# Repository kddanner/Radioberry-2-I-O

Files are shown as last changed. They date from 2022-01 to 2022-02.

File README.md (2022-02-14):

# Radioberry-2-I-O

==================

This is a simple companion board to the Radioberry 2.x to provide I/O and cooling. The minor circuitry used is shamelessly copied from the excellent [Radioberry 2](https://github.com/pa3gsb/Radioberry-2.x) and [Hermes-Lite 2](http://www.hermeslite.com) projects.

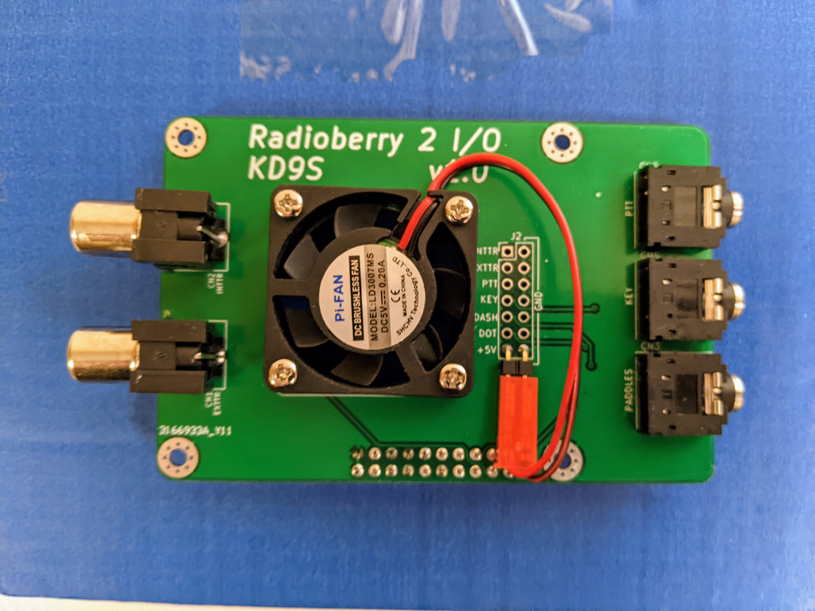
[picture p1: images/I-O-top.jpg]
Top


I tried to make this board versatile, it can be assembled multiple ways. All SMD parts are on the bottom, but all other components (header/fan/RCA jacks/3.5mm jacks) can be installed on either the top or the bottom. The board pictured has only a 2 pin header installed for the fan, but a 14 pin header can be installed for individual leads or a ribbon cable to be attached to the 5 jacks if they are mounted on a remote panel instead of directly on this board. If installing jacks on the bottom side of this board you'll need to have the SMA connectors on the bottom side of the Radioberry 2 board rather than on top as is usually done. Also, if the fan were installed on the bottom there would not be a lot of clearance between the fan and the Radioberry 2 board so you'll need low profile heatsinks and/or longer headers connecting the 2 boards to get the needed clearance. There is enough room for the I/O header to be a 90-degree header to keep the profile lower if wanted.

The zero-ohm resistors, numbered R10x are only needed when the jacks are installed on this board, and they only need to be installed in either the boxes silkscreened TOP or BTM, never both.

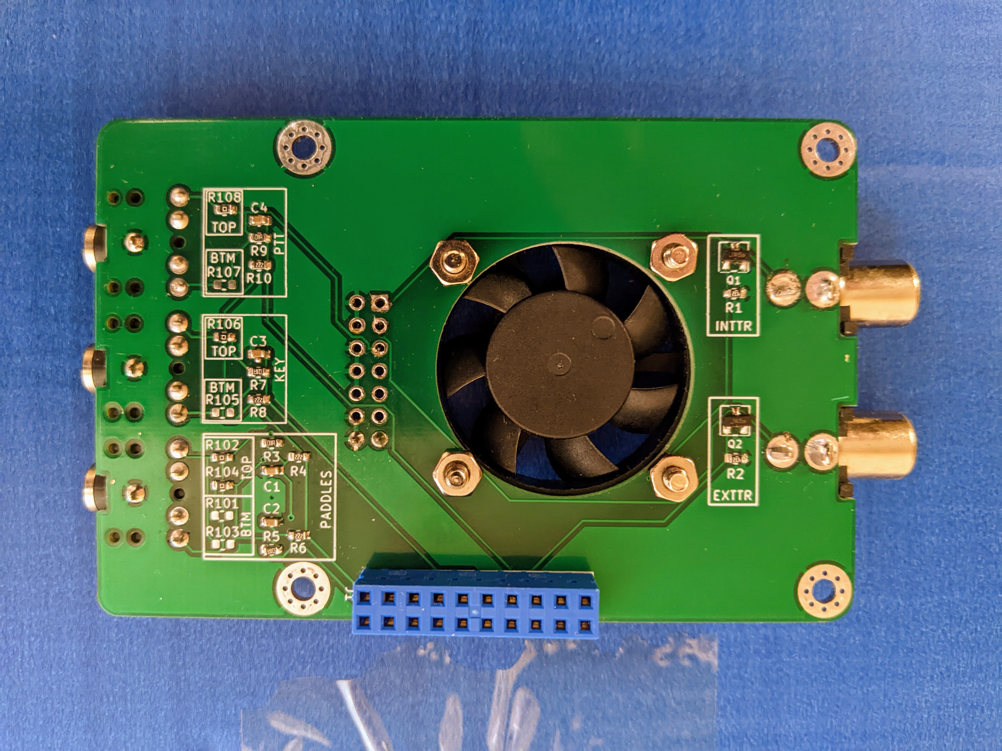
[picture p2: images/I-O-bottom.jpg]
Bottom


This cheap "case" is some of the parts from one that is meant for a pi cluster stack, available here: [Amazon link](https://www.amazon.com/gp/product/B07JP2TFJY/ref=ppx_yo_dt_b_search_asin_title?ie=UTF8&psc=1)

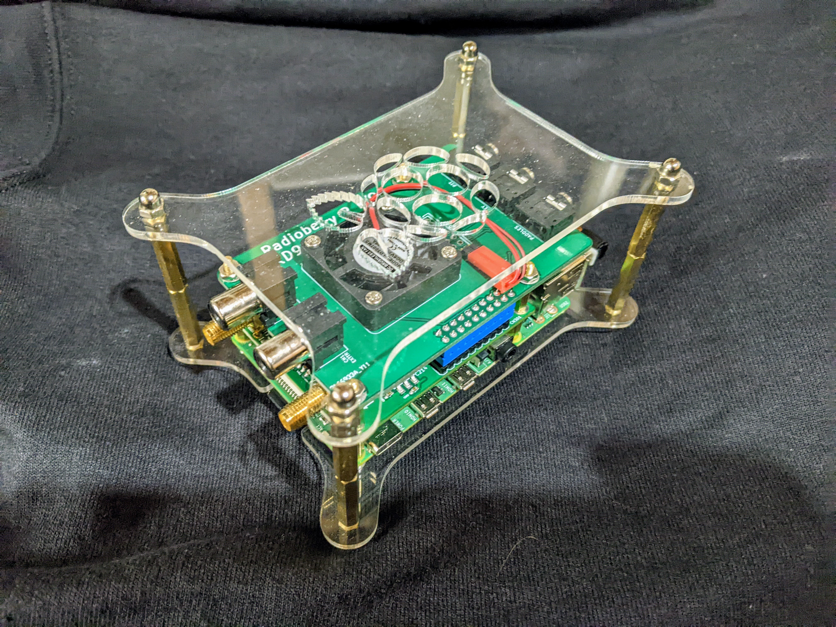
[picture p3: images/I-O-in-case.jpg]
Case


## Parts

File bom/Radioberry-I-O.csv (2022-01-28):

Source: | C:\Users\kdanner\Documents\GitHub\Radioberry-I-O\Radioberry-I-O\Radioberry-I-O.kicad_sch
Date: | 1/27/2022 5:44:45 PM
Tool: | Eeschema (6.0.1)
Generator: | C:\Program Files\KiCad\6.0\bin\scripting\plugins/bom_csv_grouped_by_value.py
Component Count: | 32
Individual Components:
Item | Qty | Reference(s) | Value | LibPart | Footprint | Datasheet | Part Number
 |  | C1 | 1uf | Device:C_Small | Capacitor_SMD:C_0603_1608Metric | https://search.murata.co.jp/Ceramy/image/img/A01X/G101/ENG/GRM188R61E105KAAD-01.pdf | GRM188R61E105KAADD
 |  | C2 | 1uf | Device:C_Small | Capacitor_SMD:C_0603_1608Metric | https://search.murata.co.jp/Ceramy/image/img/A01X/G101/ENG/GRM188R61E105KAAD-01.pdf | GRM188R61E105KAADD
 |  | C3 | 1uf | Device:C_Small | Capacitor_SMD:C_0603_1608Metric | https://search.murata.co.jp/Ceramy/image/img/A01X/G101/ENG/GRM188R61E105KAAD-01.pdf | GRM188R61E105KAADD
 |  | C4 | 1uf | Device:C_Small | Capacitor_SMD:C_0603_1608Metric | https://search.murata.co.jp/Ceramy/image/img/A01X/G101/ENG/GRM188R61E105KAAD-01.pdf | GRM188R61E105KAADD
 |  | CN1 | RCA Jack | Radioberry-I-O:Audio-Jack-2 | Radioberry-I-O:PhonoRcaRCJ-04x | https://www.cuidevices.com/product/resource/rcj-04x.pdf | RCJ-041
 |  | CN2 | RCA Jack | Radioberry-I-O:Audio-Jack-2 | Radioberry-I-O:PhonoRcaRCJ-04x | https://www.cuidevices.com/product/resource/rcj-04x.pdf | RCJ-041
 |  | CN3 | 3.5mm stereo jack | Radioberry-I-O:STEREO | Radioberry-I-O:STEREO | https://www.cuidevices.com/product/resource/sj1-352xn.pdf | SJ1-3525N
 |  | CN4 | 3.5mm stereo jack | Radioberry-I-O:STEREO | Radioberry-I-O:STEREO | https://www.cuidevices.com/product/resource/sj1-352xn.pdf | SJ1-3525N
 |  | CN5 | 3.5mm stereo jack | Radioberry-I-O:STEREO | Radioberry-I-O:STEREO | https://www.cuidevices.com/product/resource/sj1-352xn.pdf | SJ1-3525N
 |  | J1 | 2x10 female header 2.54mm | Connector_Generic:Conn_02x10_Odd_Even | Connector_PinSocket_2.54mm:PinSocket_2x10_P2.54mm_Vertical | https://cdn.amphenol-icc.com/media/wysiwyg/files/drawing/76342.pdf | 76342-310LF
 |  | J2 | 2x7 male header 2.54mm | Connector_Generic:Conn_02x07_Odd_Even | Connector_PinHeader_2.54mm:PinHeader_2x07_P2.54mm_Vertical | https://cdn.amphenol-icc.com/media/wysiwyg/files/drawing/67996.pdf | 67996-114HLF
 |  | M1 | 30mm Fan | Motor:Fan | HL2 hiflow rear endcap:fan30_big_hole | https://www.mechatronics.com/pdf/MR3010.pdf | MR3010H05B-RSR
 |  | Q1 | NUD3124LT1G | Radioberry-I-O:MOSFET_N | Radioberry-I-O:SOT23_3 | https://www.onsemi.com/pdf/datasheet/nud3124-d.pdf | NUD3124LT1G
 |  | Q2 | NUD3124LT1G | Radioberry-I-O:MOSFET_N | Radioberry-I-O:SOT23_3 | https://www.onsemi.com/pdf/datasheet/nud3124-d.pdf | NUD3124LT1G
 |  | R1 | 4.7K | Radioberry-I-O:RC0603FR-074K7L | Resistor_SMD:R_0603_1608Metric | https://www.yageo.com/upload/media/product/productsearch/datasheet/rchip/PYu-RC_Group_51_RoHS_L_11.pdf | RC0603FR-074K7L
 |  | R2 | 4.7K | Radioberry-I-O:RC0603FR-074K7L | Resistor_SMD:R_0603_1608Metric | https://www.yageo.com/upload/media/product/productsearch/datasheet/rchip/PYu-RC_Group_51_RoHS_L_11.pdf | RC0603FR-074K7L
 |  | R3 | 100 | Device:R | Resistor_SMD:R_0603_1608Metric | https://www.yageo.com/upload/media/product/productsearch/datasheet/rchip/PYu-AC_51_RoHS_L_8.pdf | AC0603FR-07100RL
 |  | R4 | 2.2k | Device:R | Resistor_SMD:R_0603_1608Metric | https://www.yageo.com/upload/media/product/productsearch/datasheet/rchip/PYu-RC_Group_51_RoHS_L_11.pdf | RC0603FR-072K2L
 |  | R5 | 100 | Device:R | Resistor_SMD:R_0603_1608Metric | https://www.yageo.com/upload/media/product/productsearch/datasheet/rchip/PYu-AC_51_RoHS_L_8.pdf | AC0603FR-07100RL
 |  | R6 | 2.2k | Device:R | Resistor_SMD:R_0603_1608Metric | https://www.yageo.com/upload/media/product/productsearch/datasheet/rchip/PYu-RC_Group_51_RoHS_L_11.pdf | RC0603FR-072K2L
 |  | R7 | 100 | Device:R | Resistor_SMD:R_0603_1608Metric | https://www.yageo.com/upload/media/product/productsearch/datasheet/rchip/PYu-AC_51_RoHS_L_8.pdf | AC0603FR-07100RL
 |  | R8 | 2.2k | Device:R | Resistor_SMD:R_0603_1608Metric | https://www.yageo.com/upload/media/product/productsearch/datasheet/rchip/PYu-RC_Group_51_RoHS_L_11.pdf | RC0603FR-072K2L
 |  | R9 | 100 | Device:R | Resistor_SMD:R_0603_1608Metric | https://www.yageo.com/upload/media/product/productsearch/datasheet/rchip/PYu-AC_51_RoHS_L_8.pdf | AC0603FR-07100RL
 |  | R10 | 2.2k | Device:R | Resistor_SMD:R_0603_1608Metric | https://www.yageo.com/upload/media/product/productsearch/datasheet/rchip/PYu-RC_Group_51_RoHS_L_11.pdf | RC0603FR-072K2L
 |  | R101 | 0 | Device:R | Resistor_SMD:R_0603_1608Metric | https://page.venkel.com/hubfs/Resources/Datasheets/CR-Series.pdf | CR0603-10W-000T
 |  | R102 | 0 | Device:R | Resistor_SMD:R_0603_1608Metric | https://page.venkel.com/hubfs/Resources/Datasheets/CR-Series.pdf | CR0603-10W-000T
 |  | R103 | 0 | Device:R | Resistor_SMD:R_0603_1608Metric | https://page.venkel.com/hubfs/Resources/Datasheets/CR-Series.pdf | CR0603-10W-000T
 |  | R104 | 0 | Device:R | Resistor_SMD:R_0603_1608Metric | https://page.venkel.com/hubfs/Resources/Datasheets/CR-Series.pdf | CR0603-10W-000T
 |  | R105 | 0 | Device:R | Resistor_SMD:R_0603_1608Metric | https://page.venkel.com/hubfs/Resources/Datasheets/CR-Series.pdf | CR0603-10W-000T
 |  | R106 | 0 | Device:R | Resistor_SMD:R_0603_1608Metric | https://page.venkel.com/hubfs/Resources/Datasheets/CR-Series.pdf | CR0603-10W-000T
 |  | R107 | 0 | Device:R | Resistor_SMD:R_0603_1608Metric | https://page.venkel.com/hubfs/Resources/Datasheets/CR-Series.pdf | CR0603-10W-000T
 |  | R108 | 0 | Device:R | Resistor_SMD:R_0603_1608Metric | https://page.venkel.com/hubfs/Resources/Datasheets/CR-Series.pdf | CR0603-10W-000T
Collated Components:
Item | Qty | Reference(s) | Value | LibPart | Footprint | Datasheet | Part Number
1 | 4 | C1, C2, C3, C4 | 1uf | Device:C_Small | Capacitor_SMD:C_0603_1608Metric | https://search.murata.co.jp/Ceramy/image/img/A01X/G101/ENG/GRM188R61E105KAAD-01.pdf | GRM188R61E105KAADD
2 | 2 | CN1, CN2 | RCA Jack | Radioberry-I-O:Audio-Jack-2 | Radioberry-I-O:PhonoRcaRCJ-04x | https://www.cuidevices.com/product/resource/rcj-04x.pdf | RCJ-041
3 | 3 | CN3, CN4, CN5 | 3.5mm stereo jack | Radioberry-I-O:STEREO | Radioberry-I-O:STEREO | https://www.cuidevices.com/product/resource/sj1-352xn.pdf | SJ1-3525N
4 | 1 | J1 | 2x10 female header 2.54mm | Connector_Generic:Conn_02x10_Odd_Even | Connector_PinSocket_2.54mm:PinSocket_2x10_P2.54mm_Vertical | https://cdn.amphenol-icc.com/media/wysiwyg/files/drawing/76342.pdf | 76342-310LF
5 | 1 | J2 | 2x7 male header 2.54mm | Connector_Generic:Conn_02x07_Odd_Even | Connector_PinHeader_2.54mm:PinHeader_2x07_P2.54mm_Vertical | https://cdn.amphenol-icc.com/media/wysiwyg/files/drawing/67996.pdf | 67996-114HLF
6 | 1 | M1 | 30mm Fan | Motor:Fan | HL2 hiflow rear endcap:fan30_big_hole | https://www.mechatronics.com/pdf/MR3010.pdf | MR3010H05B-RSR
7 | 2 | Q1, Q2 | NUD3124LT1G | Radioberry-I-O:MOSFET_N | Radioberry-I-O:SOT23_3 | https://www.onsemi.com/pdf/datasheet/nud3124-d.pdf | NUD3124LT1G
8 | 2 | R1, R2 | 4.7K | Radioberry-I-O:RC0603FR-074K7L | Resistor_SMD:R_0603_1608Metric | https://www.yageo.com/upload/media/product/productsearch/datasheet/rchip/PYu-RC_Group_51_RoHS_L_11.pdf | RC0603FR-074K7L
9 | 4 | R3, R5, R7, R9 | 100 | Device:R | Resistor_SMD:R_0603_1608Metric | https://www.yageo.com/upload/media/product/productsearch/datasheet/rchip/PYu-AC_51_RoHS_L_8.pdf | AC0603FR-07100RL
10 | 4 | R4, R6, R8, R10 | 2.2k | Device:R | Resistor_SMD:R_0603_1608Metric | https://www.yageo.com/upload/media/product/productsearch/datasheet/rchip/PYu-RC_Group_51_RoHS_L_11.pdf | RC0603FR-072K2L
11 | 8 | R101, R102, R103, R104, R105, R106, R107, R108 | 0 | Device:R | Resistor_SMD:R_0603_1608Metric | https://page.venkel.com/hubfs/Resources/Datasheets/CR-Series.pdf | CR0603-10W-000T

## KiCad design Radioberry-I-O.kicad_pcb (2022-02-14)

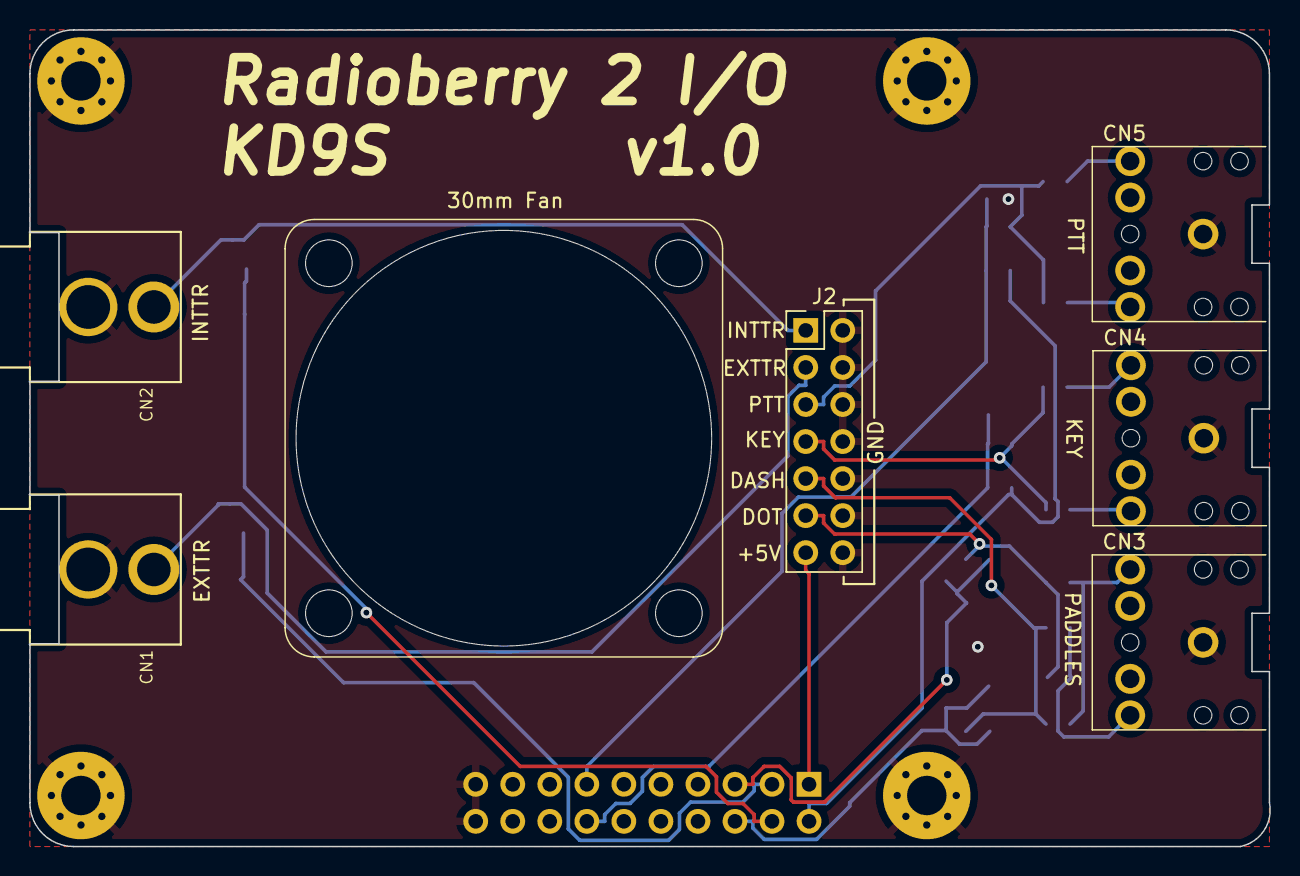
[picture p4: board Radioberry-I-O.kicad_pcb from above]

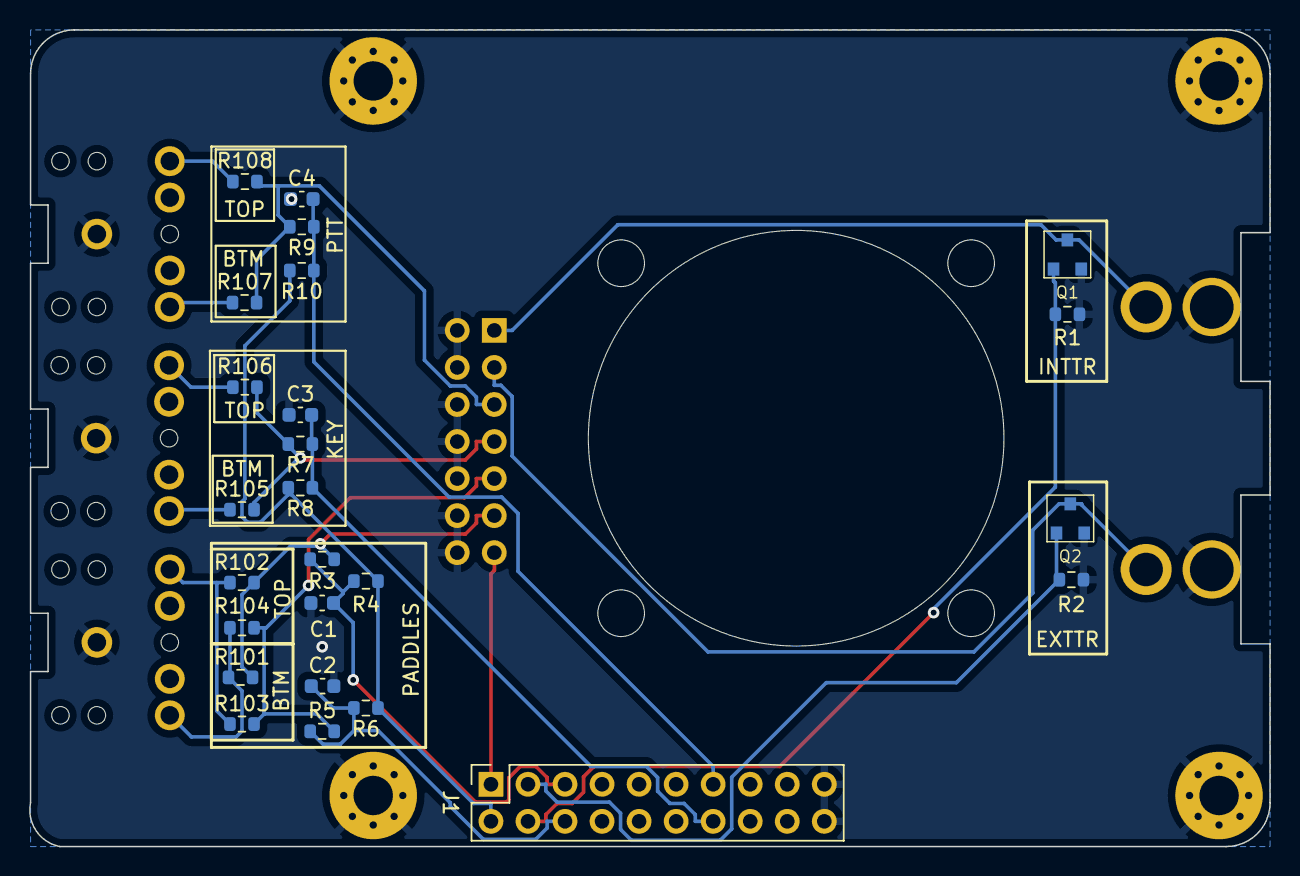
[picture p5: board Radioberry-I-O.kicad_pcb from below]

Board: 2 copper layers, 85.0 x 56.0 mm, 36 parts (25 on the bottom side), 21 nets.

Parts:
C1, C2, C3, C4: 1uf; C_0603_1608Metric
CN1, CN2: RCA Jack; PhonoRcaRCJ-04x
CN3, CN4, CN5: 3.5mm stereo jack; STEREO
J1: 2x10 female header 2.54mm; PinSocket_2x10_P2.54mm_Vertical
J2: 2x7 male header 2.54mm; PinHeader_2x07_P2.54mm_Vertical
M1: 30mm Fan; fan30_big_hole
Q1, Q2: NUD3160LT1G; SOT23_3
R1, R2: 4.7K; R_0603_1608Metric
R3, R5, R7, R9: 100; R_0603_1608Metric
R4, R6, R8, R10: 2.2k; R_0603_1608Metric
R101, R102, R103, R104, R105, R106, R107, R108: 0; R_0603_1608Metric
REF1, REF2, REF3, REF4: MountingHole_2.7mm_Pad_Via

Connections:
+3V3: J1.2, R4.2, R6.1, R8.2, R10.2
+5V: J1.1, J2.13
DASH: J2.9, R5.2, R103.2, R104.2
DOT: J2.11, R3.2, R101.2, R102.2
EXTTR: CN1.1, J2.3, Q2.3 (D)
GND: C1.1, C2.2, C3.1, C4.1, CN1.2, CN2.2, CN3.1, CN4.1, CN5.1, J1.19, J1.20, J2.2, J2.4, J2.6, J2.8, J2.10, J2.12, J2.14, Q1.2 (S), Q2.2 (S), R1.2, R2.2, REF1.1, REF2.1, REF3.1, REF4.1
INTTR: CN2.1, J2.1, Q1.3 (D)
KEY: J2.7, R7.2, R105.2, R106.2
unnamed: CN3.2, R102.1, R103.1
unnamed: CN3.3, R101.1, R104.1
unnamed: CN4.2, R106.1
unnamed: CN4.3, R105.1
unnamed: CN5.2, R108.1
unnamed: CN5.3, R107.1
PTT: J2.5, R9.2, R107.2, R108.2
rb_dash: C2.1, J1.6, R5.1, R6.2
rb_dot: C1.2, J1.5, R3.1, R4.1
rb_exttr: J1.3, Q2.1 (G), R2.1
rb_inttr: J1.4, Q1.1 (G), R1.1
rb_key: C3.2, J1.14, R7.1, R8.1
rb_ptt: C4.2, J1.13, R9.1, R10.1

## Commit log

2022-01-28 BOM cleanup
    [Radioberry-I-O.csv, Radioberry-I-O.kicad_pcb, Radioberry-I-O.kicad_sch]
2022-02-14 Update BOM & readme
    [Radioberry-I-O.csv, Radioberry-I-O.kicad_pcb, Radioberry-I-O.kicad_sch]
